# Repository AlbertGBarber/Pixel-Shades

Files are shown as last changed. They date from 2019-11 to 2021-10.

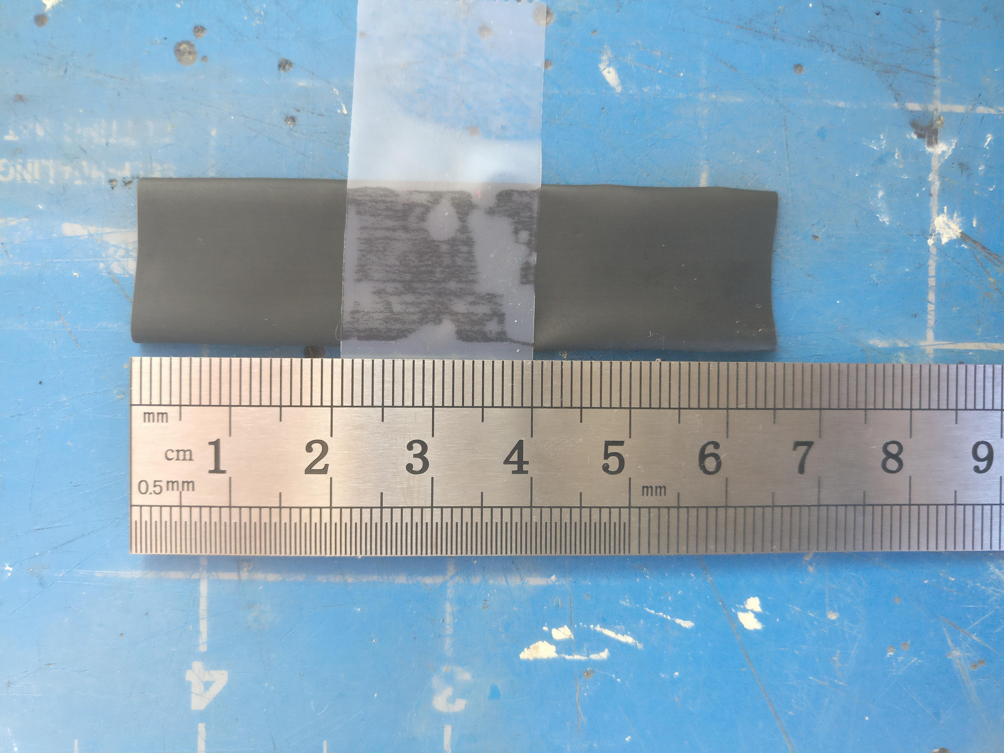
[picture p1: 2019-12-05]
Images/Temple PCB Assemble 2.jpg

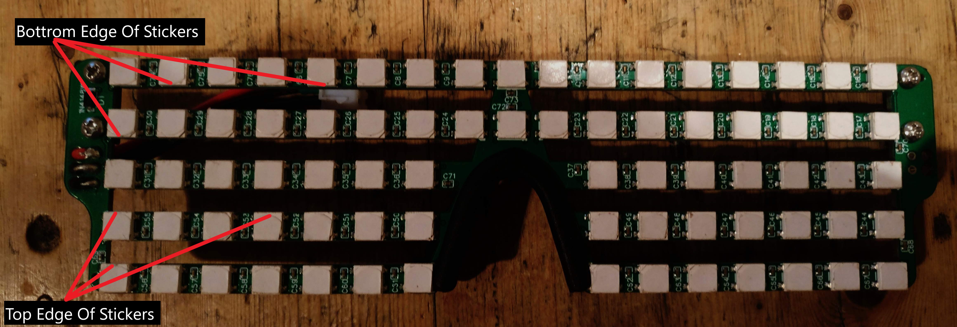
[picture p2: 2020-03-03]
Images/Shades Final Assemble 7.jpg

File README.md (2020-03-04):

# Pixel-Shades
 
 Requires my Pixel Strip library: https://github.com/AlbertGBarber/PixelStrip
 Intended to run on a ESP8266 Wemos D1 Mini. 
 
 You can find the PCBs here https://easyeda.com/splat238/ws2812-shutter-shades_copy
 
See build details here: https://www.instructables.com/id/RGB-LED-Pixel-Shades

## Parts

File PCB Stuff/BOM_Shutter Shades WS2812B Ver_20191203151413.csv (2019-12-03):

ID | Name | Designator | Footprint | Quantity | Manufacturer Part | Manufacturer | Supplier | Supplier Part | LCSC Assembly
1 | 1k | R2,R1,R8 | R0805 | 3
2 | 100K | R4,R3,R7 | R0805 | 3
3 | HC-05 | U4 | HC-05 | 1 | HC-05
4 | Header-Male-2.54_1x3 | P2 | HDR-TH_3P-P2.54-V | 1 | Header2.54mm 1*3P | BOOMELE | LCSC | C49257
5 | MCP1755ST-3302E/DB | U2 | SOT-223 | 1 | MCP1755ST-3302E/DB | Microchip Tech | LCSC | C111176 | Yes
6 | Button-SMD-4.5x4.5x5.5 | SW1,SW2,SW3 | SW-SMD_4PIN-L4.50-W4.50 | 3 | 4.5*4.5*5.5 Plastic head,260G, 0.25mm,SMD | BBJ | LCSC | C71849
7 | 1N4148W | D1 | SOD-123 | 1 | 1N4148W | STARSEA | LCSC | C89641
8 | MMBT2222A_C305427 | Q1 | SOT-23 | 1 | MMBT2222A | BLUE ROCKET | LCSC | C305427 | Yes
9 | JST_XH_3_Pin_2.54_RA | P1 | JST_XH_3_PIN_RA | 1
10 | 22 | R5 | 1206 | 1
11 | 1000uF | C5 | CAP-T7343-D | 1 | TAJE108M006RNJ | AVX | LCSC | C54883 | Yes
12 | DC-003A | J1 | DC-003A | 1 | DC-003A 3.5Jacks | BOOMELE | LCSC | C3791
13 | 1u | C2,C1,C82 | 0805' | 3
14 | 0.1u | C8,C9,C10,C11,C12,C17,C16,C15,C14,C13,C23,C24,C25,C26,C27,C22,C21,C20,C19,C18,C33,C34,C35,C36,C37,C32,C31,C30,C29,C28,C43,C44,C45,C46,C47,C42,C41,C40,C39,C38,C53,C54,C55,C56,C57,C52,C51,C50,C49,C48,C58,C59,C60,C61,C62,C67,C66,C65,C64,C63,C72,C73,C74,C75,C76,C68,C78,C77,C69,C70,C71,C81,C80,C79,C6,C7 | C0402 | 76 | CL05B104KO5NNNC | SAMSUNG | LCSC | C1525
15 | WEMOS D1 MINI | U3 | WEMOS D1 MINI | 1 | Wemos D1 mini
16 | Header-Male-2.54_1x2 | H1 | HDR-2X1/2.54 | 1 | 826629-2 | TE Connectivity | LCSC | C86471
17 | WS2812E | 0,1,2,3,4,5,6,11,10,9,8,7,17,18,19,20,21,16,15,14,13,12,27,28,29,30,31,26,25,24,23,22,37,38,39,40,41,36,35,34,33,32,47,48,49,50,51,46,45,44,43,42,52,53,54,55,56,61,60,59,58,57,66,67,68,69,70,62,72,71,63,64,65,75,74,73 | LED-5050_4P | 76 | WS2812C | Worldsemi | LCSC | C114587 | Yes
18 | MAX4466 | U1 | MAX4466 AUDIO SENSOR | 1 |  | Adafruit Industries | Adafruit Industries
19 | 1u | C3,C4 | C0805 | 2
20 | 1k | R6 | 0805' | 1

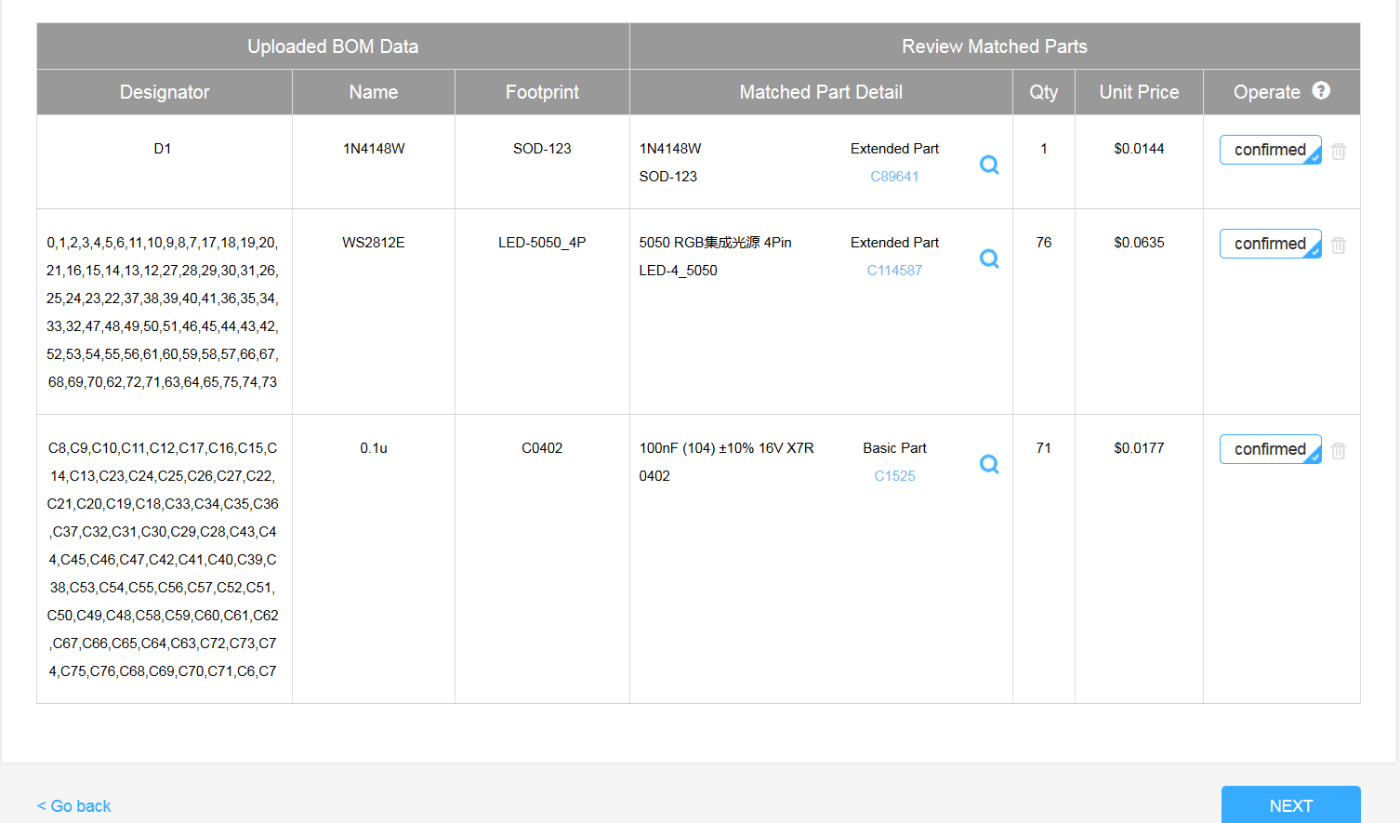
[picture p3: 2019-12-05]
Images/PCB Ordering 3.PNG

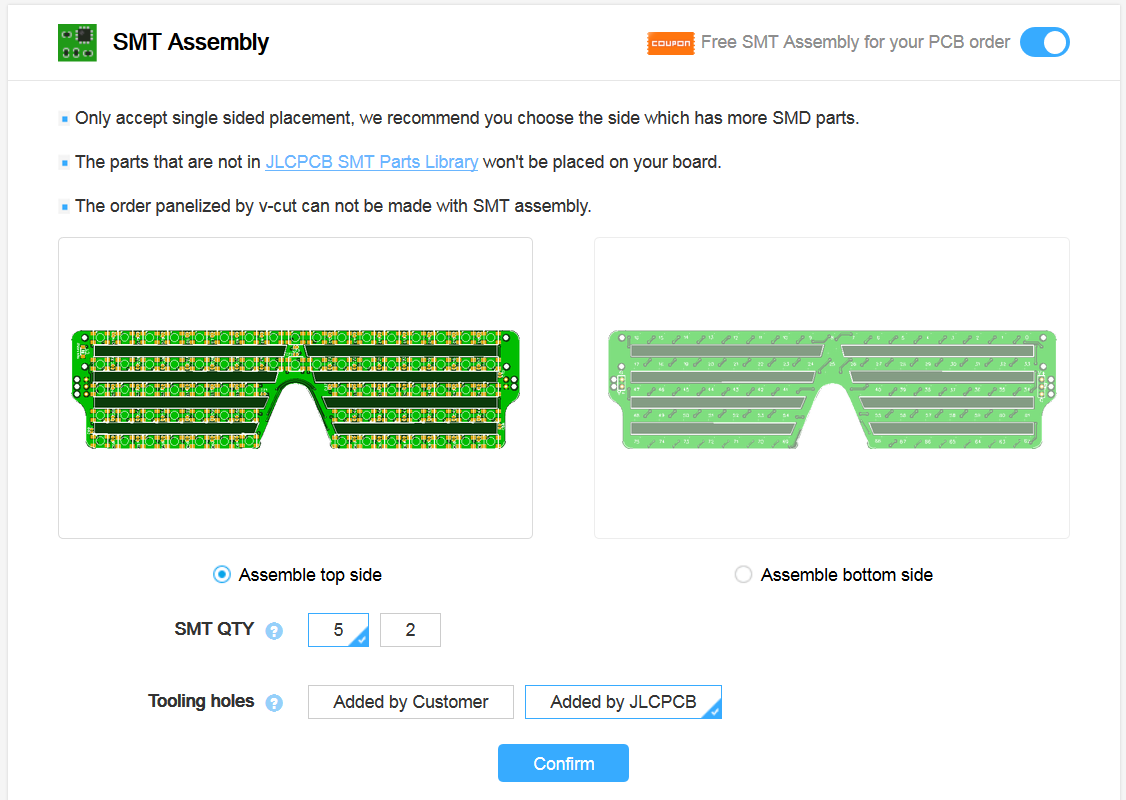
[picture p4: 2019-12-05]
Images/PCB Ordering 1.PNG

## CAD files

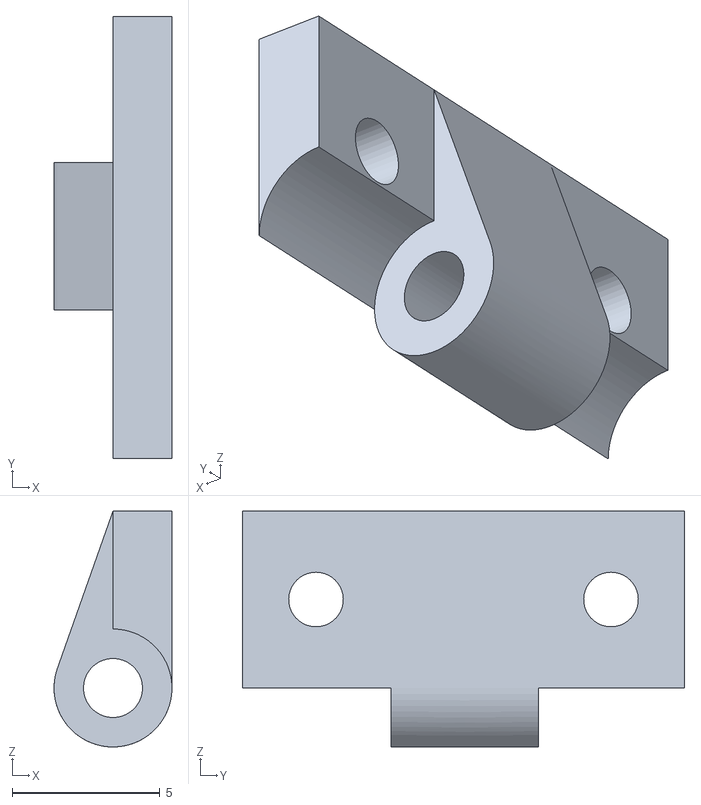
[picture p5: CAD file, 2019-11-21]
3D printed parts/hinge 2.stl
4.00 x 15.0 x 8.00

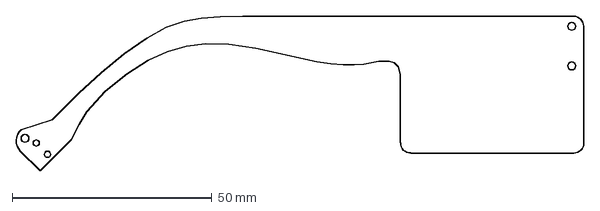
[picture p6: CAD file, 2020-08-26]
PCB Stuff/Ear Hook 1.dxf
142.3 x 38.7 mm

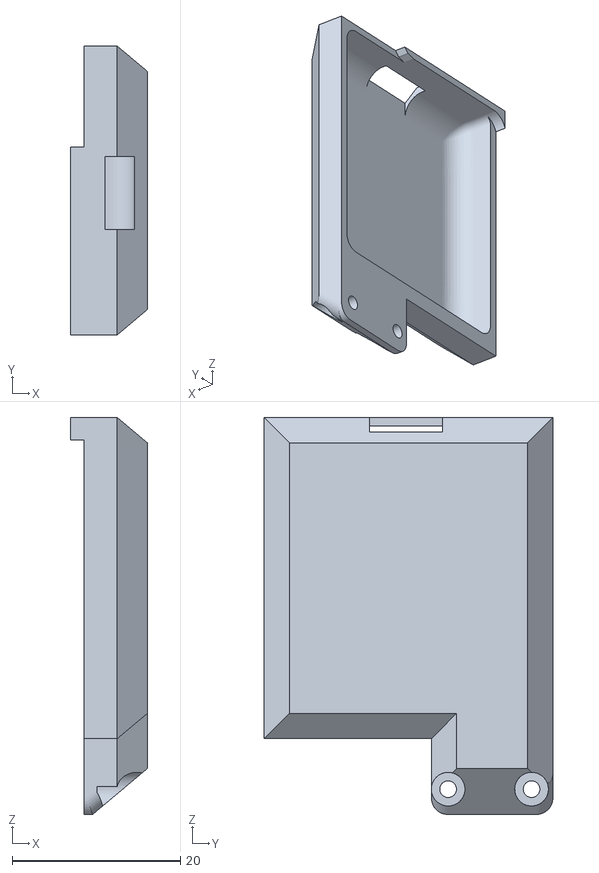
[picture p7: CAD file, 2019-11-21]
3D printed parts/Ear Cover.stl
9.10 x 34.3 x 47.1

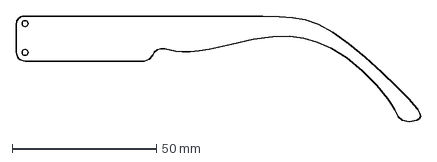
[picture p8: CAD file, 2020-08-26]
PCB Stuff/Ear Hook 2.dxf
140.0 x 36.5 mm

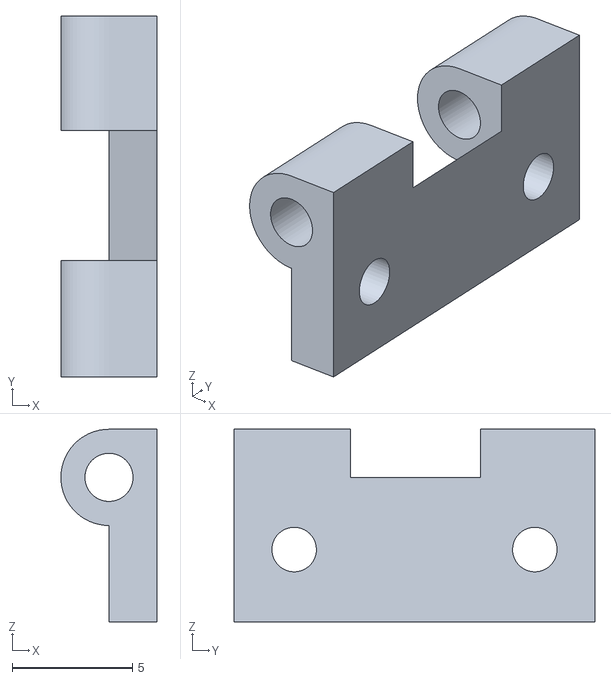
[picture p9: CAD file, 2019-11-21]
3D printed parts/hinge 1.stl
4.00 x 15.0 x 8.00

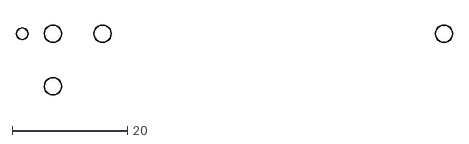
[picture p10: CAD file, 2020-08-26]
PCB Stuff/LED Placement.dxf
75.8 x 12.3

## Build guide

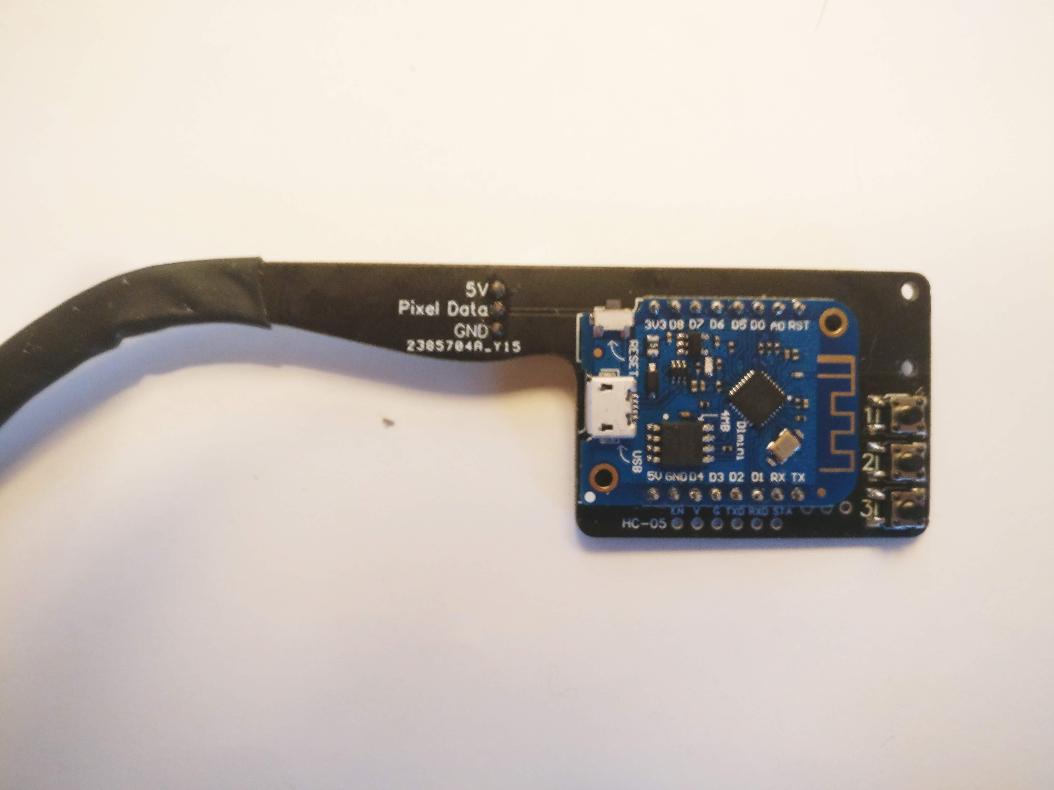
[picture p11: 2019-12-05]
Images/Temple PCB Assemble 7.jpg

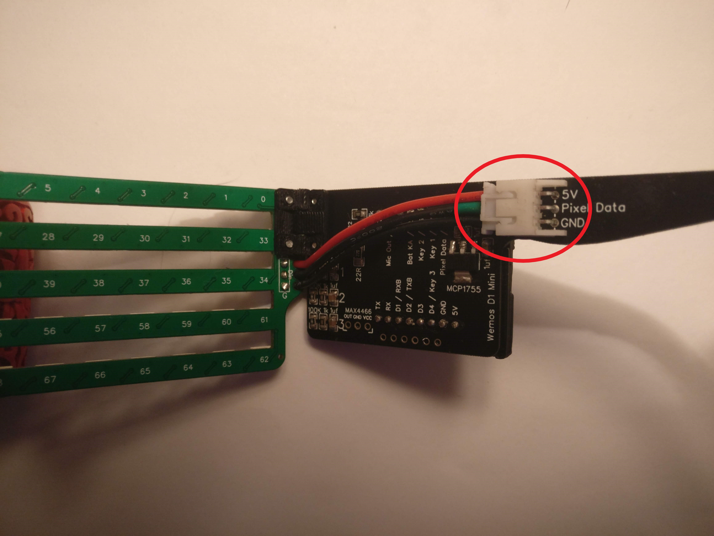
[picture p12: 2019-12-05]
Images/Shades Final Assemble 4.jpg

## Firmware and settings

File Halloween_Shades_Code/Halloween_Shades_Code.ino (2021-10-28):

//This code is placed under the MIT license
//Copyright (c) 2019 Albert Barber
//
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
//code intended to run on esp8266, Wemos D1 mini
//requires lastest version of adafruit neopixel library (use the library manager)
#include <PixelStrip.h>
#include "segmentDefs.h"

//pin connections
#define PIXEL_PIN      D8
#define BUTTON_1       D6
#define BUTTON_2       D7
#define BUTTON_3       D4
#define BAT_KEEP_ALIVE D5
//below vars are placeholders for possible bluetooth and mic board connections
#define MIC_IN         A0
#define RX_BT          D1
#define TX_BT          D2

//effects control vars
byte effectIndex = 0; //number of effect that's currently active
const byte numEffects = 40; //number of current effects - 1
boolean effectRota = true; //effects rotation on / off flag
boolean effectsStop = false; //stop all effects flag
boolean direct = true; //use for setting direction of effects
boolean breakCurrentEffect = false; //flag for breaking out of effects that use multiple sub effects / loops

//macro for implementing break for effects with multiple sub effects
#define breakEffectCheck() ({ \
    if( (breakCurrentEffect) ){ \
      (breakCurrentEffect) = false; \
      break; \
    } \
  })

//brightness vars
byte brightnessIndex = 1; //initial brightness, index of brightnessLevels array
//brightness levels array, max is 255, but 100 should be bright enough for amost all cases
//!!WARNING brightness is directly tied to power consumption, the max current per led is 60ma, this is for white at 255 brightness
//if you actually run all the leds at max, the glasses will draw 4.75 amps, this will overwhelm most power banks, and is beyond the rating of the jst connectors
const byte brightnessLevels[] = { 10, 20, 30, 50, 70, 100 };
const byte numBrightnessLevels = SIZE( brightnessLevels );

//time settings for battery keep alive
//if using something other than an ESP8266, you'll need to adjust the timer code to work with whatever timers your chip has
//power banks shutdown unless a minimum current is pulled within a certain time period
//The BAT_KEEP_ALIVE pin is connected to a NPN transistor, which, when triggered, allows about 200ma to pass through a resistor
//the pin is triggered by an ISR based on the esp8266's timer1 internal clock
//the below variables set the times for triggering the transistor, adjust them as need for your power bank
//each tick is 0.2us, so ticks Needed = ( desired Time (in sec) ) / .0000002 (this depends on the clock freq used during ISR setup)
const uint32_t BAT_KEEP_ALIVE_FREQ = 25000000; //5 sec; how often the keep alive is activated
const uint32_t BAT_KEEP_ALIVE_INTERV = 1000000; //0.2 sec; how long the keep alive stays active for
const uint32_t BAT_KEEP_ALIVE_START_DELAY = 1000000; //0.2 sec; inital delay for starting the keep alive cycle
//(more than enough time for the setup function to finish)
//Strip definitions
const uint16_t stripLength = 76;
const uint8_t stripType = NEO_GRB + NEO_KHZ800;
PixelStrip strip = PixelStrip(stripLength, PIXEL_PIN, stripType);

//Define some colors we'll use frequently
const uint32_t white =    strip.Color(255, 255, 255);
const uint32_t off =      strip.Color( 0, 0, 0 );

const uint32_t orangeHalwen = strip.Color(250, 65, 19); //strip.Color(253,119,8);
const uint32_t yellowHalwen = strip.Color(253, 229, 0);
const uint32_t greenHalwen = strip.Color( 43, 208, 17 );
const uint32_t purpleHalwen = strip.Color(174, 3, 255); //strip.Color(137,41,191);
const uint32_t blueHalwen = strip.Color( 16, 124, 126 );
const uint32_t brownOrangHalwen = strip.Color(92, 16, 9);

const uint32_t pastelRainbow = strip.Color(130, 185, 226); //178,231,254,
const uint32_t pastelRainbow1 = strip.Color(110, 46, 145); //purple
const uint32_t pastelRainbow2 = strip.Color(54, 174, 218); //teal
const uint32_t pastelRainbow3 = strip.Color(120, 212, 96); //green
const uint32_t pastelRainbow4 = strip.Color(255, 254, 188); //yellow
const uint32_t pastelRainbow5 = strip.Color(236, 116, 70); //orange
const uint32_t pastelRainbow6 = strip.Color(229, 61, 84); //pink red

//define pallet array, contains 32bit representations of all colors used in patterns
uint32_t pallet[] = { off, white };
//                   { -0-, --1--}

uint32_t halloweenPallet[] = { greenHalwen, purpleHalwen, orangeHalwen, brownOrangHalwen, off };
//                              -----0-----  ------1-----  -----2------  ------3----      -4--

//removes the off and brown color
uint32_t halloweenSubPallet[] = { greenHalwen, purpleHalwen, orangeHalwen, brownOrangHalwen };
//                                 -----0-----  ------1-----  -----2------   ------3----  

byte halloweenWavePattern[4] = { 0, 1, 2, 3 };

uint32_t pastelRainbowPallet[] = { pastelRainbow, pastelRainbow1 , pastelRainbow2, pastelRainbow3, pastelRainbow4, pastelRainbow5, pastelRainbow6 };
byte pastelRainbowPattern[] = {  6, 1, 2, 5, 4, 3, 0 };

//byte wavepattern[]  = { 0, 0, 1, 1 };
//byte wavepattern2[] = { 2, 2, 0, 0 };
//byte wavepattern3[] = { 3, 3, 2, 2 };
//byte wavepattern4[] = { 2, 2, 1, 1 };
//byte halloweenWavePattern[4] = { 0, 1, 2, 3 };

//below are spin patterns
//these are for use with the colorSpin function, which draws a pattern across segments (using the longest segment as the pattern basis)
//and then moves it along the longest segment
//you can make your own, their structure is the following
//(note that you'll have to understand how segments work in my library, you can find notes on segments in segmentSet.h)
//a spin pattern is comprised of two parts combined into one 1d array
// { 0, 1,   1, 2, 0, 0, 0, }
//  part 1       part 2
//part 1 indicates the leds on the longest segment that part 2 is to be drawn on (doesn't inculde the last index, so 1 above wouldn't be drawn)
//part 2 is the pattern of colors for each segment, made up of indeces for at pallet (ie 1 represents the second color in the pallet)

//this is confusing so I'll give an example
//for the glasses, using lenseRowSegments (each row of the glasses is a segment, excluding the center 6 leds so that all the rows are the same length)
//part 1 above indicates that, from the 0th led of the first segment, up to (not including) the 1st led, the color pattern of the segments is part 2
//the result is that the first led of each row are colored (using pallet above) row 0 -> white, row 1 -> uclaGold, row 2 -> off,  row 3 -> off, row 4 -> off
//note that leds indexs in part 1 are always defined using the longest segment, because colorSpin will map the pattern (part 1) onto shorter segments
//this works well on most led arrangments, but not so much on the glasses
//which is why I'm using lenseRowSegments, so that all segments are equal length, and the mapping is one to one

//as below, spin patterns can have multiple pattern sections
//you define the matrix as: spinPatternName[(5 + 2) * 8] -> [ (number of segments + 2) * number of rows in pattern ]
//you can also make patterns repeat using colorSpin, so you just have to define a single complete pattern (like I do with spinPatternWave)

//for rowLenseSegments
//two color sine wave pattern
byte spinPatternWave[(5 + 2) * 8] = {
  0, 1,   1, 2, 0, 0, 0,
  1, 2,   0, 1, 2, 0, 0,
  2, 3,   0, 0, 1, 2, 0,
  3, 4,   0, 0, 0, 1, 2,
  4, 5,   0, 0, 0, 1, 2,
  5, 6,   0, 0, 1, 2, 0,
  6, 7,   0, 1, 2, 0, 0,
  7, 8,   1, 2, 0, 0, 0,
};

//for rowLensesHalvesSegments, we want rows seperated, so we can move the arrows in opposite directions
//two color arrows, moving horizontally
//if you want vertical arrows, you have to use columnSegments
byte spinPatternArrows[(10 + 2) * 5] = {
  0, 1,   1, 0, 0, 0, 1, 1, 0, 0, 0, 1,
  1, 2,   2, 1, 0, 1, 2, 2, 1, 0, 1, 2,
  2, 3,   0, 2, 1, 2, 0, 0, 2, 1, 2, 0,
  3, 4,   0, 0, 2, 0, 0, 0, 0, 2, 0, 0,
  4, 5,   0, 0, 0, 0, 0, 0, 0, 0, 0, 0,
};

//for columnSegments, an arrow in each lense
byte spinPatternArrowsVert[(17 + 2) * 5] = {
  0, 1,   2, 0, 0, 0, 0, 0, 2, 0, 0, 0, 2, 0, 0, 0, 0, 0, 2,
  1, 2,   1, 2, 0, 0, 0, 2, 1, 0, 0, 0, 1, 2, 0, 0, 0, 2, 1,
  2, 3,   0, 1, 2, 0, 2, 1, 0, 0, 0, 0, 0, 1, 2, 0, 2, 1, 0,
  3, 4,   0, 0, 1, 2, 1, 0, 0, 0, 0, 0, 0, 0, 1, 2, 1, 0, 0,
  4, 5,   0, 0, 0, 1, 0, 0, 0, 0, 0, 0, 0, 0, 0, 1, 0, 0, 0,
};

//for rowLenseSegments, USA flag
byte spinPatternUSflag[(5 + 2) * 4] = {
  0, 1,   4, 1, 4, 6, 1,
  1, 2,   1, 4, 1, 6, 1,
  2, 3,   4, 1, 4, 6, 1,
  3, 8,   1, 6, 1, 6, 1,
};

//for rowLenseSegments, St George's cross (can't get blue right for Union Jack)
byte spinPatternStGeorgeCross[(5 + 2) * 3] = {
  0, 3,   1, 1, 6, 1, 1,
  3, 4,   6, 6, 6, 6, 6,
  4, 7,   1, 1, 6, 1, 1,
};

//storage for pallets we'll generate on the fly
uint32_t tempRandPallet[5]; //pallet for random colors (length sets number of colors used by randomColors effect)
uint32_t tempTwinklePallet[2]; //used for twinkle effect, we are only twinkling two colors at a time

//battery keep alive ISR
//(pulses a NPM transistor at regular intervals to pull current from the power bank, preventing it from shutting down due to low current draw)
//when called, if BatKeepAliveOn is true, we turn off the transistor, and set the timer delay to the BAT_KEEP_ALIVE_FREQ
//otherwise, we turn on the transistor and set the timer delay to BAT_KEEP_ALIVE_INTERV
//ie we switch between truning the transistor on and off, while waiting either BAT_KEEP_ALIVE_FREQ or BAT_KEEP_ALIVE_INTERV
//before turing it on/off again
//if using something other than an ESP8266, you'll need to adjust this code to work with whatever timers your chip has
boolean BatKeepAliveOn = false;
void ICACHE_RAM_ATTR BatKeepAlive_ISR() {
  if (BatKeepAliveOn) {
    digitalWrite(BAT_KEEP_ALIVE, LOW); //turn off transistor
    timer1_write(BAT_KEEP_ALIVE_FREQ); //set next trigger time
  } else {
    digitalWrite(BAT_KEEP_ALIVE, HIGH); //turn on transistor
    timer1_write(BAT_KEEP_ALIVE_INTERV); //set next trigger time
  }
  BatKeepAliveOn = !BatKeepAliveOn;
}

//triggered by button 1, stops the current pattern, and switches to the next one, wrapping if needed
//if button 2 is also being held, turn effects on / off
void ICACHE_RAM_ATTR nextEffect() {
  strip.pixelStripStopPattern = true; //stop the current pattern
  breakCurrentEffect = true; //set flag to break out of current case statement
  //if button 2 is being held, stop/start the effect cycle
  //otherwise increase the index to start the next effect
  if ( digitalRead(BUTTON_2) == LOW) {
    effectsStop = !effectsStop;
  }
}

//triggered by button 2, turns effect rotation on / off
//(if rotation is off, the current effect will be repeated continuously)
//if button 1 is also being held, turn effects on / off
void ICACHE_RAM_ATTR effectRotaToggle() {
  if ( digitalRead(BUTTON_1) == LOW) {
    strip.pixelStripStopPattern = true;
    effectsStop = !effectsStop;
  } else {
    effectRota = !effectRota;
  }
}

//triggered by button 3, sets the strip brightness to the next
//brightness level in the brightnessLevels array (wrapping to the start if needed)
void ICACHE_RAM_ATTR brightnessAdjust() {
  brightnessIndex = (brightnessIndex + 1) % numBrightnessLevels;
  strip.setBrightness( brightnessLevels[ brightnessIndex ] );
}

//increments the effect index (wrapping if needed)
void incrementEffectIndex() {
  effectIndex = (effectIndex + 1) % numEffects;
}

void setup() {
  //initalize the led strip, and set the starting brightness
  strip.begin();
  strip.setBrightness( brightnessLevels[brightnessIndex] );

  //configure the button and bat keep alive pins
  pinMode(BAT_KEEP_ALIVE, OUTPUT);
  pinMode(BUTTON_1, INPUT_PULLUP);
  pinMode(BUTTON_2, INPUT_PULLUP);
  pinMode(BUTTON_3, INPUT_PULLUP);
  //because of the way my library currently works, effects occupy the processor until they end
  //so to break out of an effect, or change sytem values, we need to use interrupts
  attachInterrupt(digitalPinToInterrupt(BUTTON_1), nextEffect, FALLING);
  attachInterrupt(digitalPinToInterrupt(BUTTON_2), effectRotaToggle, FALLING);
  attachInterrupt(digitalPinToInterrupt(BUTTON_3), brightnessAdjust, FALLING);

  //attach an timer interrupt for keeping the power bank alive, and start it
  //if using somkething other than an esp8266, you'll need to adjust this code to work with the timers on your chip
  timer1_attachInterrupt(BatKeepAlive_ISR);
  timer1_enable(TIM_DIV16, TIM_EDGE, TIM_SINGLE); //TIM_DIV16 ==> each tick is 0.2us
  timer1_write(BAT_KEEP_ALIVE_START_DELAY); //start the ISR timer

  strip.show();
  //Serial.begin(115200);

  randomSeed(ESP.getCycleCount()); //generate a random seed
  //fill in our random pallet
  strip.genRandPallet( tempRandPallet, SIZE(tempRandPallet) );
}

//!! If you want to change the main loop code, please read all the comments below and in the loop !!
//To remove an effect, simply change its case # to anything greater than the total number of effects (999 for ex)
//if you want to know about certain effects, please see comments in the library for said effect
//if you want to know how segments work, please see comments in segmentSet.h

//The main loop of the program, works as follows:
//if effectsStop is true, effects are "off", so we won't try to start the next effect
//otherwise we jump to the effect matching the effectIndex value using a switch statment
//we also "clean up" a bit by reseting direct to true and the breakCurrentEffect flag to false
//if we don't find an effect with the effectIndex, we increment the effectIndex until we do
//while an effect is running, button inputs can either lock the effect or skip to the next effect
//if we lock the effect (set effectRota to false), we do not increment effectIndex when the effect ends, essentially restarting the effect (with new colors if they're randomly choosen)
//if the effect is skipped, we set strip.pixelStripStopPattern and breakCurrentEffect to true
//strip.pixelStripStopPattern will stop the current effect, and breakCurrentEffect will break out of the current switch statement if needed (the switch case has more than one effect)
//once the effect ends (either naturally or from a button press), we incremented effectIndex (as long as effectRota is set true)
//and jump to the top of the main loop

void loop() {

  if (!effectsStop) { //if effectsStop is true, we won't display any effect
    direct = true;
    breakCurrentEffect = false;
    //switch statment contains all effects
    //I'm not going to comment each one, as they're hard to describe
    //if an case has a loop, it generally means the effect will by run multiple times in diff directions
    //these will contain breakEffectCheck(); which will breakout of the case if the effect is skipped by button input
    //segmentName.flipSegDirectionEvery(1, true) means that the direction of the names segments will be reversed
    //this is used to change the direction of colorSpin effects
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

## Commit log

2019-11-21 Inital Commit
    [BOM_Shutter Shades WS2812B Ver_20191008111357.csv, Ear Cover.stl, PickAndPlace_Shades Ws2812B_20191008110459.csv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]
2019-11-23 Changed buttons on PCB
2019-12-03 Updated Gerbers
2019-12-03 updated BOM and P&P to remove outdated ws2812b
    [BOM_Shutter Shades WS2812B Ver_20191008111357.csv, BOM_Shutter Shades WS2812B Ver_20191203151413.csv, PickAndPlace_Lenses Ws2812B_20191203151443.csv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]
2019-12-05 Renamed PCB files and added construction images
2020-08-26 re organized files
    [BOM_Shutter Shades WS2812B Ver_20191203151413.csv, Ear Cover.stl, Ear Hook 1.dxf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]
